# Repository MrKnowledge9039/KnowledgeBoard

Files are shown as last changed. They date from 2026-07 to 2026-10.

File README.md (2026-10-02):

# KnowledgeBoard
 Hi! This is my submission for hackpad as part of stardance program! This was made for Hackpad v5 as part of stardance mission.

## Overview
 My very first hardware project: My own Macropad called KnowledgeBoard (I know very creative), completely designed by me, with 3x3 Keys, each with a SK6812 MINI-E and 2 Rotary Encoders as well as KMK firmware. I made it because I like learning new things. Multiple times I thought macro board would be very useful but I always worked around it instead of building one. And with the opportunity of Hackpad I wanted to try to build a macroboard that suits my needs. It should be compact, simple and at the same time versatile for different jobs like replacing a Streamdeck and improving the workflow with Krita or DMXC.

## PCB
 Here are pictures of my PCB:

| **Schematic** | **PCB** |
|---|---|
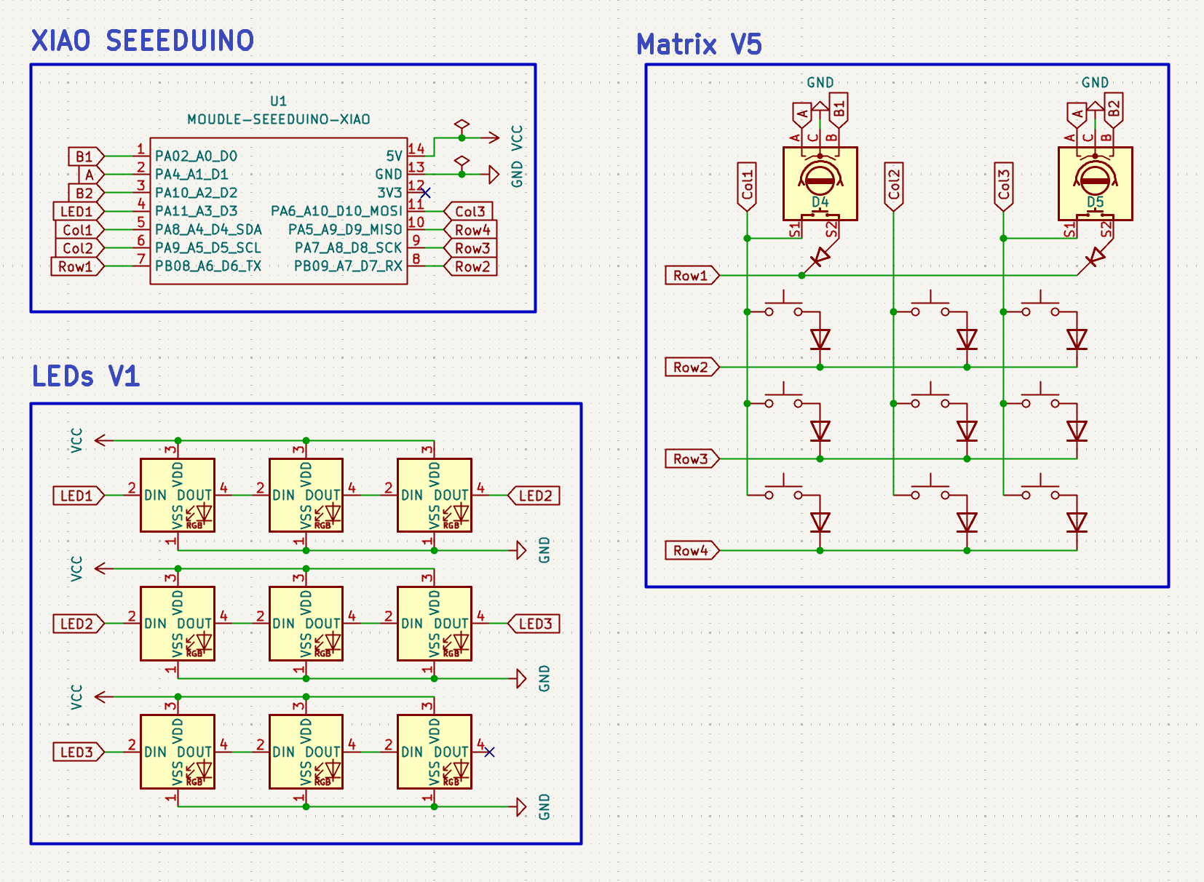
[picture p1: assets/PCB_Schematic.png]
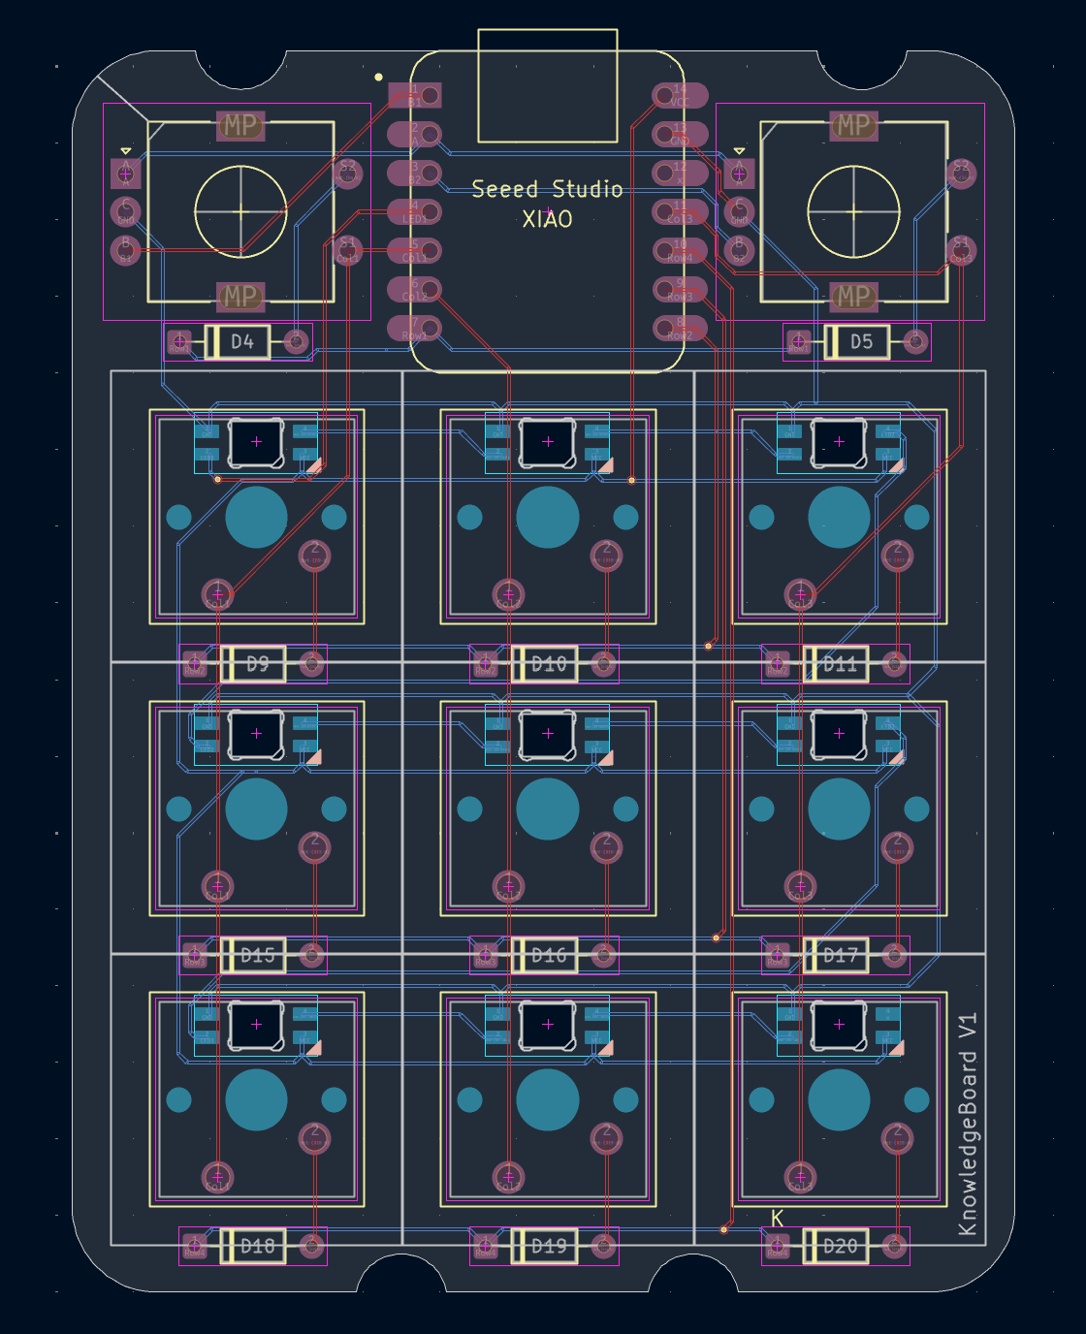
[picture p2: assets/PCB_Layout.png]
|||

## CAD
The Case Top and Bottom were designed using onshape. It helped that I had some experience in with 3D-Design. It was compared to that because I only used Extrude nothing complicated. Assembled are the separate case parts through screws.
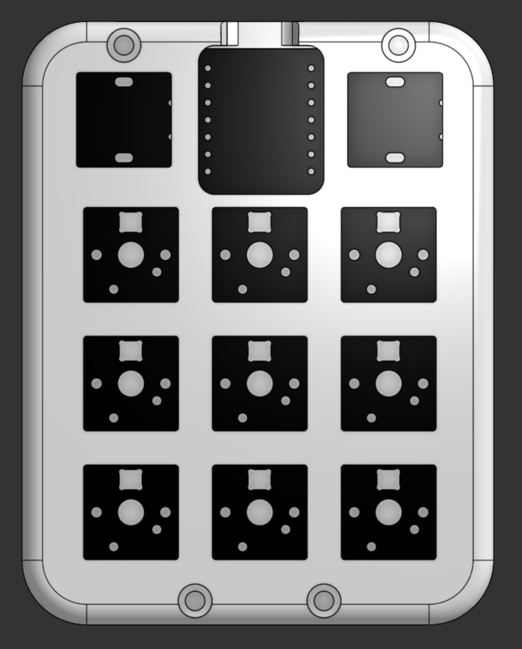
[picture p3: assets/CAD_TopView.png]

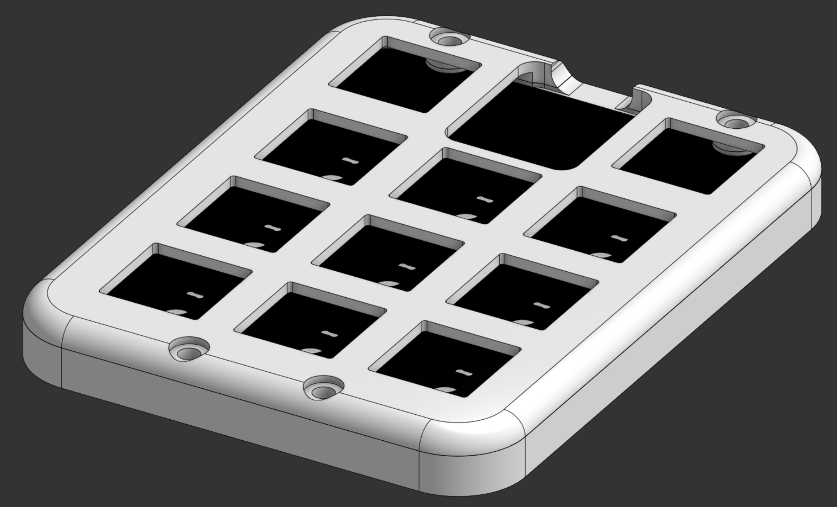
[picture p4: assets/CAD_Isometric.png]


## Firmware

The firmware is KMK, because it seemed easier for this project then QMK and is pretty small but has every feature the board uses and supports multiple layers.

## Notes
Making the pad was great and I will definitely progress doing also hardware projects. The Hackpad is a great starting point to get into this PCB/3D-Design.

## BOM
- 1 SEEEDUINO XIAO RP2040
- 9x MX-Style switches
- 9x white blank DSA keycaps(I try to replace them with frosted ones)
- 11x 1N4148 diodes
- 9x SK6812-MINI-E LED
- 2x EC11 Rotary encoders
- 4x M3x16mm screws
- 4x M3x16mm heatset inserts

## License
 CC-BY-SA

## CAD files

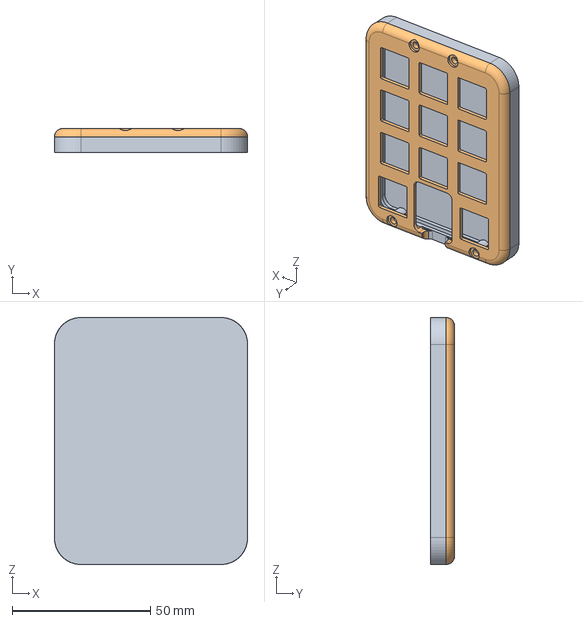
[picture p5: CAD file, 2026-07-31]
cad/KnowledgeBoard-Case.step
69.9 x 8.70 x 89.4 mm

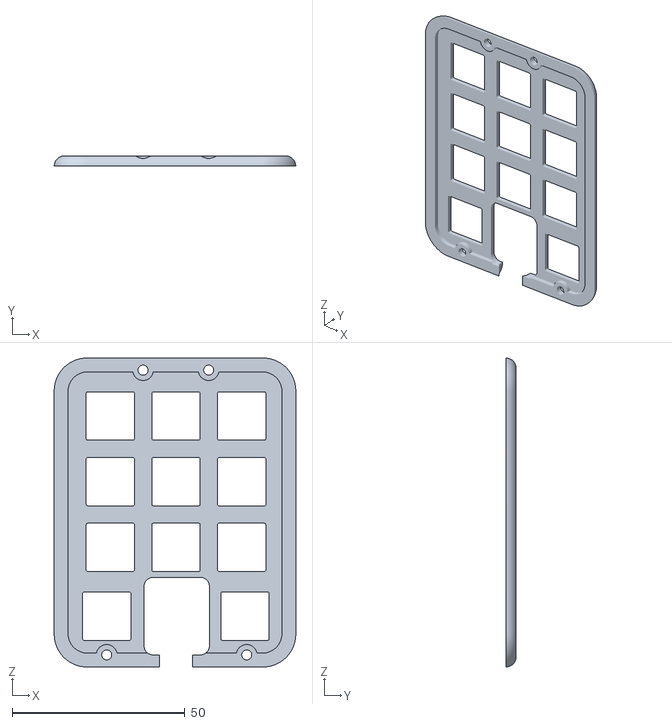
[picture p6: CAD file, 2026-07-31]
production/KnowledgeBoard-Case Top.stl
69.9 x 3.00 x 89.4

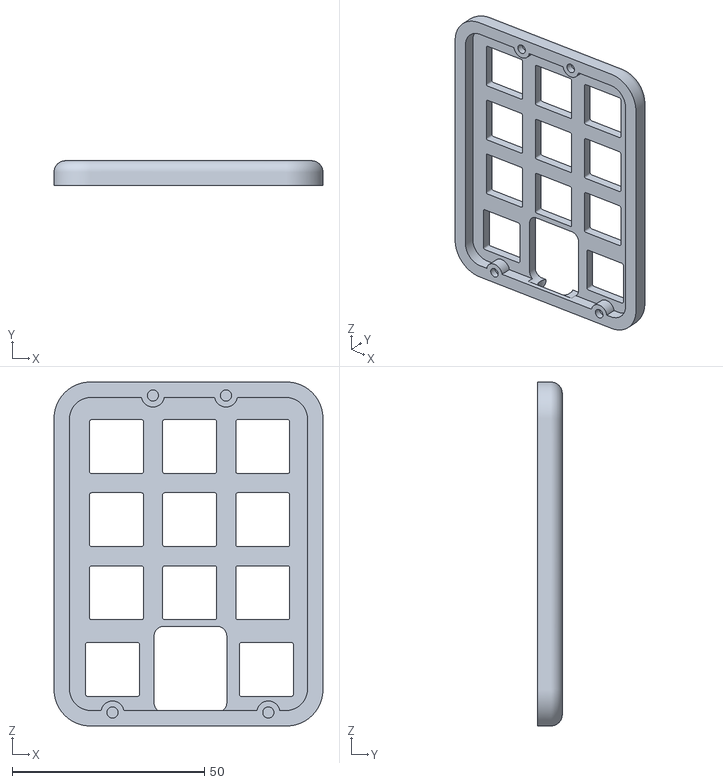
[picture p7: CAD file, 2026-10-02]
production/moreCAD/V1.1/KnowledgeBoard V1.1 - Case Top.stl
69.9 x 6.40 x 89.4

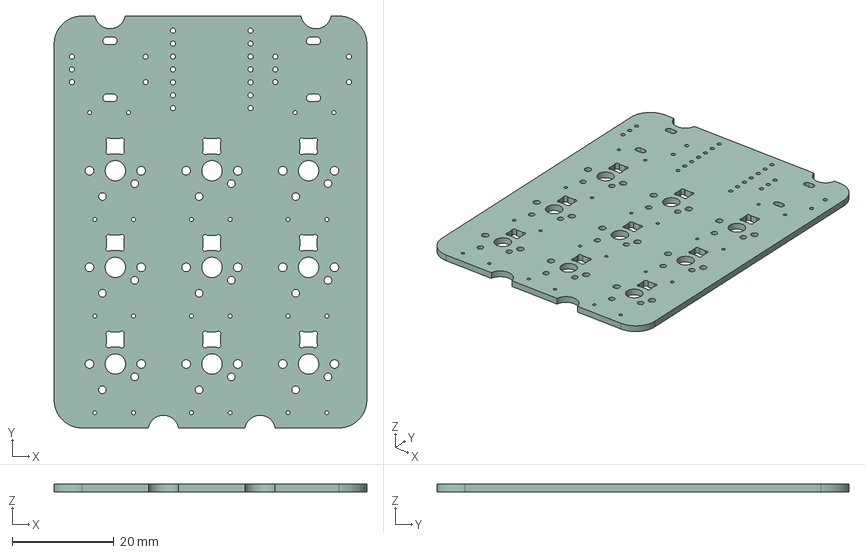
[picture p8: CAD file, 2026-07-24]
cad/KnowledgeBoard_PCB.step
61.5 x 81.0 x 1.51 mm

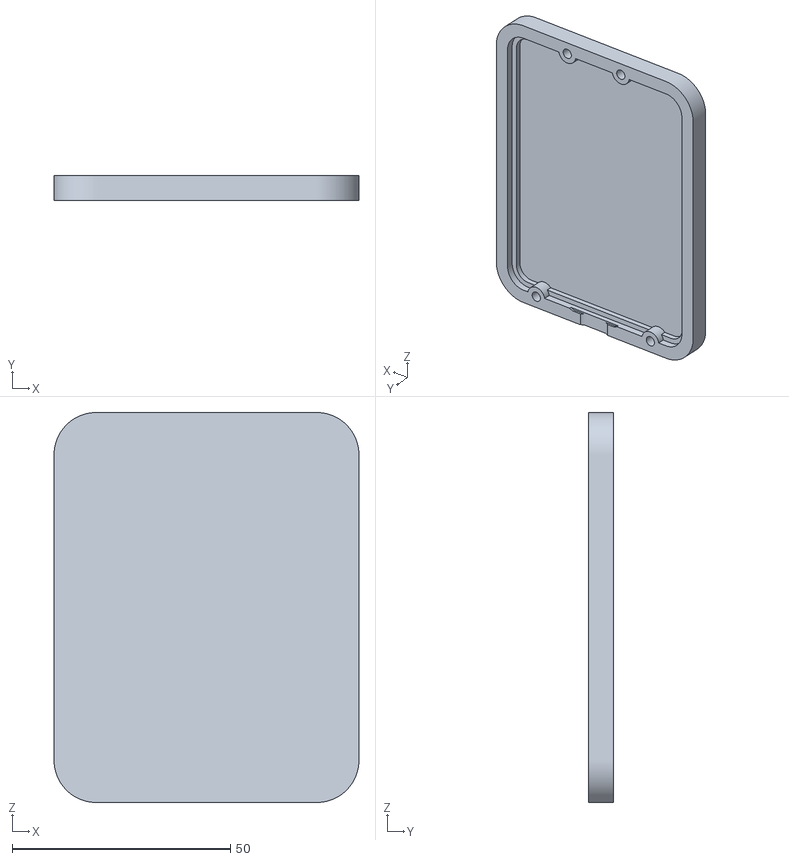
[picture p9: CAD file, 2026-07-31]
production/KnowledgeBoard-Case Bottom.stl
69.9 x 5.70 x 89.4

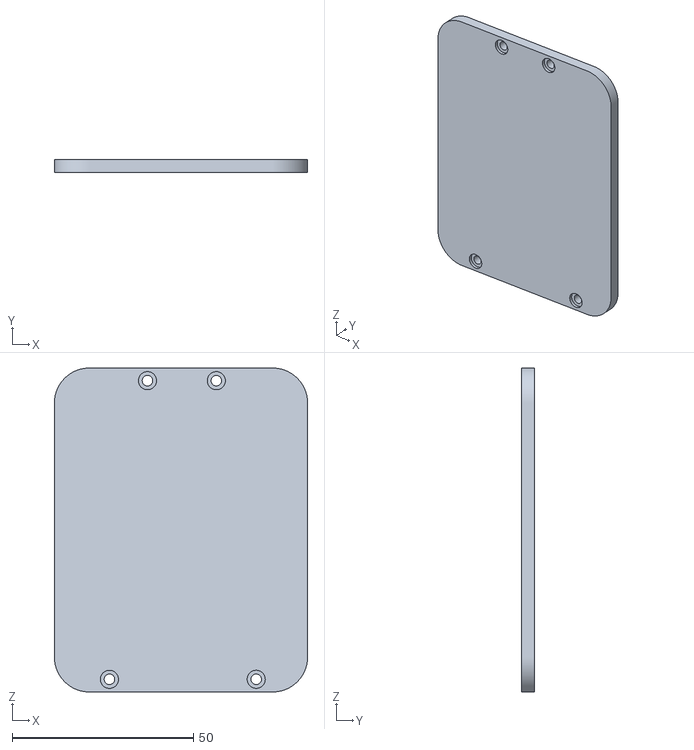
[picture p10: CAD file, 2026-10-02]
production/moreCAD/V1.1/KnowledgeBoard V1.1 - Case Bottom.stl
69.9 x 3.60 x 89.4

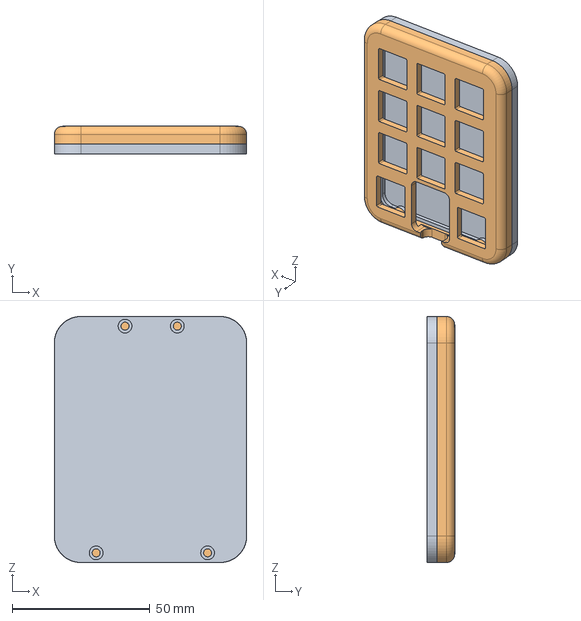
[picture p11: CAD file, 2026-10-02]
production/moreCAD/V1.1/KnowledgeBoard V1.1.step
69.9 x 10.0 x 89.4 mm

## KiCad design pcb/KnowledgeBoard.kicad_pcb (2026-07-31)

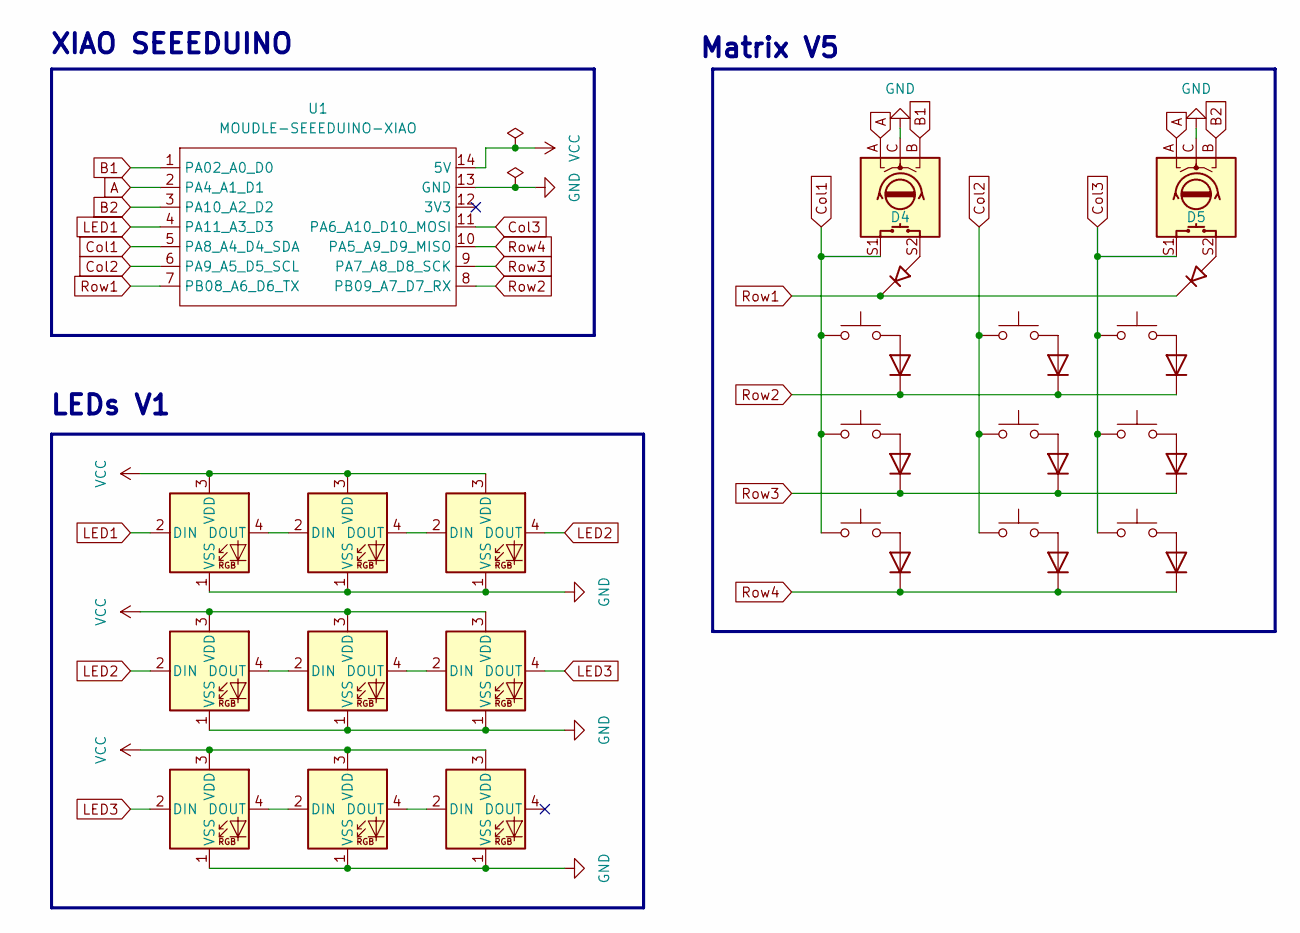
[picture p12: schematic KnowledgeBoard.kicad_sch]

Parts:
D1, D2, D3, D6, D7, D8, D12, D13, D14: SK6812MINI-E; SK6812MINI-E_fixed
D4, D5: D_45deg; D_DO-35_SOD27_P7.62mm_Horizontal
D9, D10, D11, D15, D16, D17, D18, D19, D20: 1N4148; D_DO-35_SOD27_P7.62mm_Horizontal
SW1, SW2: RotaryEncoder_Switch; RotaryEncoder_Alps_EC11E-Switch_Vertical_H20mm
SW3, SW4, SW5, SW6, SW7, SW8, SW9, SW10, SW11: SW_Push; SW_Cherry_MX_1.00u_PCB
U1: MOUDLE-SEEEDUINO-XIAO; XIAO-Generic-Hybrid-14P-2.54-21X17.8MM

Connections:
A: SW1.A, SW2.A, U1.2 (PA4_A1_D1)
B1: SW1.B, U1.1 (PA02_A0_D0)
B2: SW2.B, U1.3 (PA10_A2_D2)
Col1: SW1.S1, SW3.1, SW6.1, SW9.1, U1.5 (PA8_A4_D4_SDA)
Col2: SW4.1, SW7.1, SW10.1, U1.6 (PA9_A5_D5_SCL)
Col3: SW2.S1, SW5.1, SW8.1, SW11.1, U1.11 (PA6_A10_D10_MOSI)
GND: D1.1 (VSS), D2.1 (VSS), D3.1 (VSS), D6.1 (VSS), D7.1 (VSS), D8.1 (VSS), D12.1 (VSS), D13.1 (VSS), D14.1 (VSS), SW1.C, SW2.C, U1.13 (GND)
LED1: D1.2 (DIN), U1.4 (PA11_A3_D3)
LED2: D3.4 (DOUT), D6.2 (DIN)
LED3: D8.4 (DOUT), D12.2 (DIN)
unnamed: D1.4 (DOUT), D2.2 (DIN)
unnamed: D2.4 (DOUT), D3.2 (DIN)
unnamed: D4.2 (A), SW1.S2
unnamed: D5.2 (A), SW2.S2
unnamed: D6.4 (DOUT), D7.2 (DIN)
unnamed: D7.4 (DOUT), D8.2 (DIN)
unnamed: D9.2 (A), SW3.2
unnamed: D10.2 (A), SW4.2
unnamed: D11.2 (A), SW5.2
unnamed: D12.4 (DOUT), D13.2 (DIN)
unnamed: D13.4 (DOUT), D14.2 (DIN)
unnamed: D15.2 (A), SW6.2
unnamed: D16.2 (A), SW7.2
unnamed: D17.2 (A), SW8.2
unnamed: D18.2 (A), SW9.2
unnamed: D19.2 (A), SW10.2
unnamed: D20.2 (A), SW11.2
Row1: D4.1 (K), D5.1 (K), U1.7 (PB08_A6_D6_TX)
Row2: D9.1 (K), D10.1 (K), D11.1 (K), U1.8 (PB09_A7_D7_RX)
Row3: D15.1 (K), D16.1 (K), D17.1 (K), U1.9 (PA7_A8_D8_SCK)
Row4: D18.1 (K), D19.1 (K), D20.1 (K), U1.10 (PA5_A9_D9_MISO)
VCC: D1.3 (VDD), D2.3 (VDD), D3.3 (VDD), D6.3 (VDD), D7.3 (VDD), D8.3 (VDD), D12.3 (VDD), D13.3 (VDD), D14.3 (VDD), U1.14 (5V)

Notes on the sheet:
Matrix V5
XIAO SEEEDUINO
LEDs V1

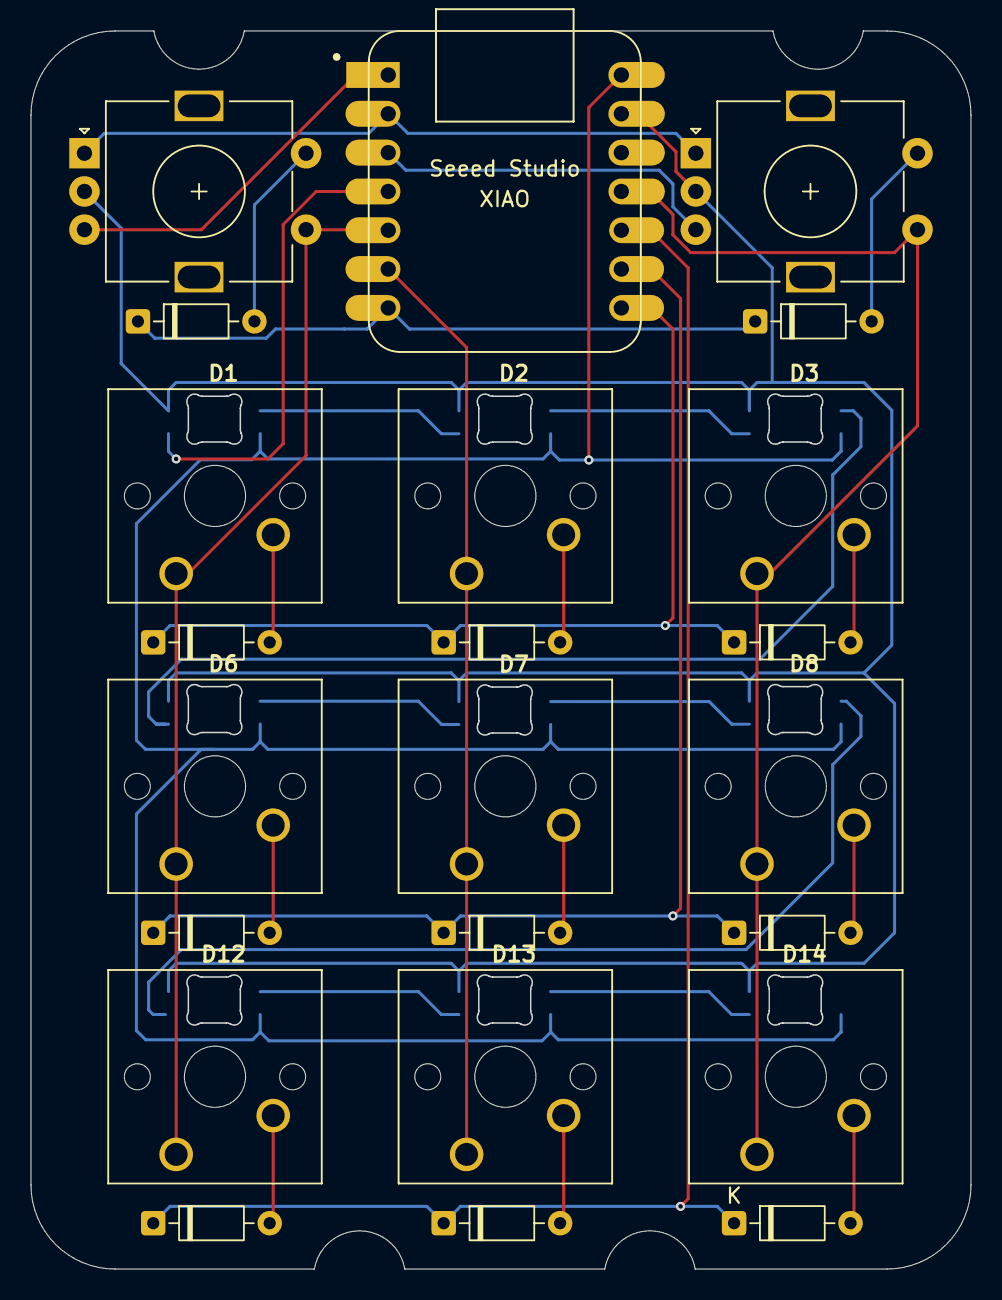
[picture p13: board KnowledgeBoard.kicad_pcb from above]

Board: 2 copper layers, 61.5 x 81.0 mm, 32 parts (0 on the bottom side), 32 nets.

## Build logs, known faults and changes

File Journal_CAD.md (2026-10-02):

# KnowledgeBoard CAD Journal

## Oktober 2
 So to start my Atlantis journey i upgraded my KnowledgeBoard case design. Now the screws are at the bottom, out of sight, and not any longer visible on top.

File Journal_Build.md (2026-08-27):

# KnowledgeBoard Build Journal

## August 22
 I got the Hackpad kit and the PCB delivered. The PCB was great, it was funny to me to see the digital version I designed beeing so accurately beeing manufactured. It was like it came straight out of my screen. And after giving everything a look I wanted to assemble and solder everything. Before soldering though I tried wheather the XIAO would work and it did. So I started soldering with the diodes and LEDs (ik it's Light-Emitting-Diode) and then soldered the XIAO to try again. And it did't work, so my approach was to solder the switches and rotary encoders and try it fully soldered but it still didn't work. It gave me an "Power Surge on USB port" error. 

Time: ca. 3h
 
## August 23
 I tried to fix this problem using another USB port but it still didn't work. I also double checked everything that could cause a shortcircuit and I also checked the directions of all the diodes and LEDs. But nothing fixed my issue. So I asked for help in #help and #electronics and some very nice people tried to help me but unfortunately they could not fix my problem (or at least not the power surge problem). I tried to desolder everything to try it on another PCB but I only could get the switches removed the rest I will do when I get access to a heat gun.

Time: ca. 1h

## August 25, 26
### Desoldering parts
 With access to a heat gun I got the XIAO off the PCB and tried it and ot worked completely fine. Great so I could go on. I desoldered some of the diodes and LEDs, enough that with the ones I had not used, I could build the MacoBoard again. I reused the switches too. But unfortunately the rotary encoders stopped working after the attempt of getting them off. 

### Second attempt
 Too start my second try I took a second of my PCBs and soldered the XIAO onto it. It still worked great. After that I added the diodes for the key matrix. Worked! I went on with the switches. Worked! Next I tried the LEDs and solderd two of them on and checked if it still would work but it didn't. So I desoldered them again and tried if I could get the keys to actually function. And I tried some simple code to check if they work and they did. Great!

### First SK6812 MINI-E Problem
 After a closer look on my PCB design and the datasheet of the SK6812 MINI-E I found what caused the problem and how to fix it. I had used the Footprint Library of the Hackpad tutorial for the SK6812 MINI-E and the little triangle marking that showed how to solder the LED was on the opposite corner than it should be according to the datasheet. So I roated the SK6812 MINI-E 180° and this solved the first problem. I would not get the power surge error anymore. Great!

### Second SK6812 MINI-E Problem
 After the first problem was solved but the LEDs still would not light up, I searched for the origin of this problem and there the nice people in #help and #electronics helped me. The noticed that I powered the LEDs with 5V but the logic would be send at 3.3V and because the LEDs would first recognise an logic "1" or "on" above 3.5V the LEDs wouldn't light up. My solution for this was to destroy the 5V power line for the LEDs and creating a new one using a thin wire from 3.3V to the LEDs-power line. And as a result the LEDs worked. Great! I was soo happy!

 I will order new EC11 rotary encoders and try to complete my KnowledgeBoard.

Time ca. 4h 30min

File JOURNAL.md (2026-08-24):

# KnowledgeBoard Design Journal

# June 28
## First Exploration of KiCAD
Made the basic 3 key Hackpad exmaple to get a feeling for KiCAD, Schematic and PCB Editing
I was very supprised to see how easy designing a PCB is and that you dont need any previous knowledge.

## Schematic Editing
  Added every all Parts including their footprints (I hope I chose the right one for the rotary encoder) I needed for my favoured design.
  Through inspiration by other Hackpads i made the Matrix (also QMK Matrix Explanation) and the backlighting daisy chain.
  After adding the rotary encoders I discovered that i had to few pins on the XIOA to add 3 rotary encoders and lighting and the rotary encoder switches.
  My idea was to add the rotary encoders also to the matrix to have less pin usage (2 columns more instead of 2 (A/B) per rotary encoder),
  because I found a youtube video where rotary encoders were explained as having offsetted binary signals to determine the rotation.
  So it's like a key getting pressed or not and i found no reason why this shouldn't work. *later I found one

## PCB Editing
  First I rotated every switch so I could place the LEDs behind each switch not infront.
  Secondly I placed the three rotary encoders beside the 3x3 key "panel".
  After that I arranged every diode to it's optimal place (rearranged it later to make space for the XIAO).
  I tried multiple times wiring the row and col sections first and then the LEDs but it got each time to messy so I tried again.
  My next approach was to wire the LEDs first but that wasn't optimal. Afterwards I discovered that vias exist so I tried again and it worked like a charm.

Research: How to work with LED, Rotary-Encoders for Schematic and PCB editing and stuff.

Time: ca. 7h

# June 29
  Although the rewiring helped and after I changed the pin assignment on the XIAO the wiring got quite good and I thought I was nearly ready, I discovered two other issues.
### Issue 1:
  I cramed the XIAO, the LED and the Switch on the exact point on the PCB which obiously does not work. so I needed to move the LED and XIAO.
  (I thought the XIAO could go on the bottom side and the switch was designed so the LED would fit on the same side as the switch, I have never done this)
### Issue 2:
  The trick with adding the rotation pins to the matrix does not work, because the code checks the matrix each row at a time,
  but the rotation pins need to be checked all the time to work.

Research: Why these things don't work and how to fix them.

# June 30 / July 1,2,3
  I startet all over again and changed my design to have two rotary encoders and placed them on the top, not on the side as before.
  And made my design the design symetrical with the XIAO at the top between the rotary-encoders.
  I finished the design made the schematic, used a better way to align the items then the auto clamp when dragging,
  paid attention to put everything on the side it should be wired everything. And thought again I could go on with making the 3D-CAD, but no.
  I ran the DRC and I got multiple issues. 36 of them were the same. Every footprint of the LEDs had the same 4 issues. The pads were to close to the Edge.cuts layer.
  So I first looked on other projekts and how they solved the problem. They had smaler pads, so i thought ok good where do I find this library.
  I didn't find it so I thought good, then I'll try to make a footprint similar to the one that worked for the other projekt.
  And it worked. But because of this and because I wanted the rotation knobs on the side and not on the top it wanted it to remake it again.

Time ca. 5h

# July 5
 Starting all over again I chose to just make the design upright and just use a angled cable if needed.
 I first changed the schematic slightly and fixed two Input/Output Power Issue, using PWR-Flags. After that I again placed, wired and fixed all the issues left. Then I made the final Form of the PCB in the edge.cuts layer. And there I was ready with my PCB and on to the next part.

Time ca. 3h

# July 11,12,18,19
 Designing the 3D case for the PCB. First importing the PCB, then making a 3mm margin around it and adding a part to hold the pcb while still having enough space for the PCB parts on the bottom. Additionally adding a simple integrated plate to clip in the switches. After the first design I made two more. One with a bigger body and a seperate integrated plate and another one with a smaller body, which is at the same time the plate the swtiches clip to. Very helpful for this was the [Hackpad design of Devin Myers](https://cad.onshape.com/documents/fadd4340fdcb2f9894b9d56e/w/4e9dbccf657b58782bca758e/e/4c2b640b6a0422cb6de851e2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). I thought I wil use so I completed the bigger and left the smaller version unfinished.

 Time ca. 7h

# July 21,22
 For the firmware I chose KMK because it's esier and more simpel then QMK and I needed to install just Python. After downloading the release of CircuitPython for the XIAO I looked at the firmware of my inspiration and then used the very good documentation on github(the website documentation is gone) to complete it with the rotary encoders, the keys and the LEDs.

 Time ca. 2h

# July 23
 After reviewing everything I discovered that the smaller case I chose to use had no holes for the heat insets. So I added that (also had also to change the Edge.Cuts Layer on the PCB). It was nice to be so quick with everything after the first attempt took so long.

 Time ca. 30min

# July 31
 As I was looking around in Slack " discovered that the DRC-footprint problem was a problem that many people ran into and the go to solution was apparently to just ignore the DRC errors. I changed the footprints back to the recomended ones used in the tutorial and also added tolerances off 0.2mm and now my board is pre-flight checked.

 Time ca. 20min

Note at the end:
 KiCAD has apparently a tool that autoroutes the wires... I wish I knew earlier.

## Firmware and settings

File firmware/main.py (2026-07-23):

print("Starting")

import board

from kmk.kmk_keyboard import KMKKeyboard
from kmk.keys import KC
from kmk.modules.layers import Layers
from kmk.modules.encoder import EncoderHandler
from kmk.extensions.media_keys import MediaKeys
from kmk.extensions.RGB import RGB

keyboard = KMKKeyboard()
layers = Layers()
encoder_handler = EncoderHandler()

rgb = RGB(pixel_pin=board.GP3, num_pixels=9)
keyboard.extensions.append(rgb)

keyboard.modules = [layers, encoder_handler]
keyboard.extensions.append(MediaKeys())

keyboard.col_pins = (board.GP4, board.GP5, board.GP10)
keyboard.row_pins = (board.GP6, board.GP7, board.GP8, board.GP9,)


Zoom_in = KC.LCTRL(KC.EQUAL)
Zoom_out = KC.LCTRL(KC.MINUS)

encoder_handler.pins = (
    (board.GP0, board.GP1, None), # encoder #1 
    (board.GP2, board.GP1, None), # encoder #2
    )

LayerNum = 0

LUP = KC.FD(LayerNum - 1) if LayerNum > 0 else KC.FD(0)
LDN = KC.FD(LayerNum + 1) if LayerNum < 5 else KC.FD(5)

encoder_handler.map = [ (( KC.VOLD, KC.VOLU), (KC.BRID, KC.BRIU),), # Default
                        ((Zoom_out, Zoom_in), (KC.LBRC, KC.RBRC),), # Zoom / Krita Layer will get upgrade
                        ((KC.RIGHT, KC.LEFT), (KC.DOWN, KC.UP),),   # DMXC Pos
                        ((KC.MS_RT, KC.MS_LT), (KC.MW_UP, KC.MW_DN),),   # Move Mouse
                        ((KC.FD(LUP), KC.FD(LDN)), (KC.NO, KC.NO),),   # Switch Layer
                      ]


class LayerRGB(RGB):
    def on_layer_change(self, layer):
        if layer == 0:
            rgb.set_hsv(170, self.sat_default, self.val_default, 0) # blue
        elif layer == 1:
            rgb.set_hsv(170, self.sat_default, self.val_default, 1)
        elif layer == 2:
            rgb.set_hsv(170, self.sat_default, self.val_default, 2)
        elif layer == 4:
            rgb.set_hsv(170, 0, self.val_default, 3)               
        elif layer == 4:
                    rgb.set_hsv(170, 0, self.val_default, 3)       
        # update the LEDs manually if no animation is active:
        self.show()



keyboard.keymap = [
    [
        KC.MO(5), KC.NO, KC.MUTE,
        KC.N1, KC.N2, KC.N3,
        KC.N4, KC.N5, KC.N6,
        KC.N7, KC.N8, KC.N9,
    ],
    [
        KC.MO(5), KC.NO, KC.MUTE,
        KC.F13, KC.F14, KC.F15,
        KC.F16, KC.F17, KC.F18,
        KC.F19, KC.F20, KC.F21,
    ],
    [
        KC.MO(5), KC.NO, KC.MUTE,
        KC.N1, KC.N2, KC.N3,
        KC.Q, KC.W, KC.E,
        KC.A, KC.S, KC.D,
    ],
    [
        KC.MO(5), KC.NO, KC.MUTE,
        KC.RGB_HUI, KC.RGB_HUD, KC.RGB_TOG,
        KC.RGB_VAI, KC.RGB_VAD, KC.NO,
        KC.NO, KC.NO, KC.NO,
    ]
]

rgb.set_hsv_fill(0, 0, rgb.val_default)

if __name__ == '__main__':
    keyboard.go()

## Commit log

2026-06-29 Add initial journal entry for KiCAD exploration
    Start of the journal and first entry to KiCAD and starting MyHackpad Design
2026-07-21 Update (Big)
    [Case-Bottom.stl, Case-Top.stl, KnowledgeBoard.kicad_pcb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]
2026-07-24 Adding documentation and final design changes
    [Case Bottom.stl, Case Top.stl, Case-Bottom.stl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]
2026-07-31 Pre-flight ready
    [Case Bottom.stl, Case Top.stl, KnowledgeBoard-Case Bottom.stl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]
2026-08-07 Rename KnowledgeBoard_PCB.step
    [KnowledgeBoard_PCB.step]
2026-10-02 CAD improvement
    [KnowledgeBoard V1.1 - Case Bottom.stl, KnowledgeBoard V1.1 - Case Top.stl, KnowledgeBoard V1.1.step]
2026-10-02 cad journal
